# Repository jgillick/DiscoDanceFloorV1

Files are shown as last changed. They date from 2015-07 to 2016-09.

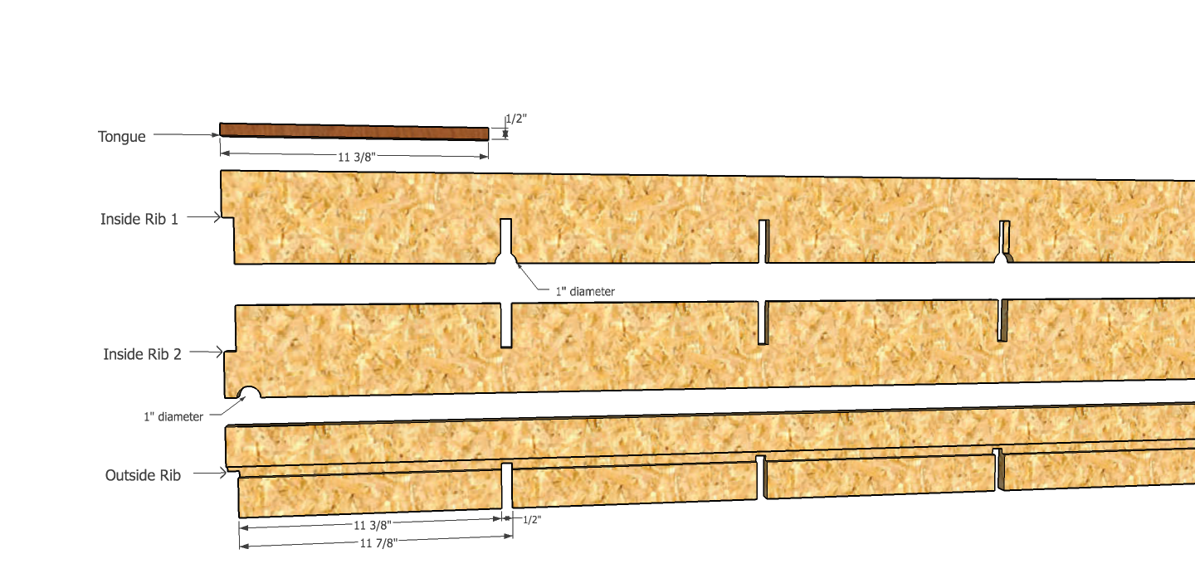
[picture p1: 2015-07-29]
Construction/Exports/RibDimensions.png

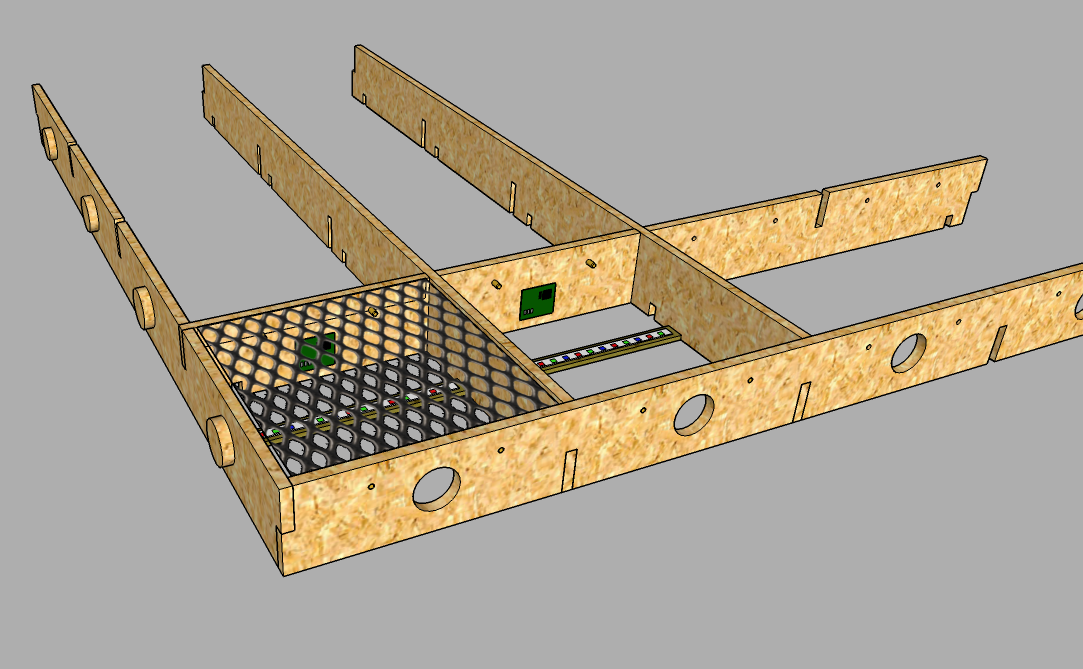
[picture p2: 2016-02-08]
Construction/Exports/FloorCell2.png

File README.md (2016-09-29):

# Disco Dance Floor

Saturday night fever

This project is for a full-size interactive dance floor that can respond to touch and sound.

The floor is made up of individually controlled squares (nodes) attached to a computer via an
RS485 bus. Each node has an Atmega328 with RGB LEDs and a capacitive sensor to detect someone
standing over that cell.

The master controller uses Node.js and provides a simple API that can be used to
write custom floor control programs.

## More information
More information about the build can be found on my page at [hackaday.io](https://hackaday.io/project/4209-interactive-disco-dance-floor).

Touch sensors

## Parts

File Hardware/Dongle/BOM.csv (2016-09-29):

Id | Designator | Package | Quantity | Designation | Supplier and ref
1 | J1 | RJ45_8 | 1 | RJ45
2 | P1 | USB_B | 1 | USB_B
3 | D2 | LED_0805 | 1 | RX
4 | D1 | LED_0805 | 1 | TX
5 | R1,R2,R4,R3 | R_0805 | 4 | 200
6 | C1,C4,C5 | C_0805 | 3 | 100nF
7 | C2 | C_0805 | 1 | 4.7uF
8 | C3 | C_0805 | 1 | 10nF
9 | D3 | LED_0805 | 1 | D
10 | D4 | LED_0805 | 1 | S
11 | R5,R6,R8 | R_0805 | 3 | 20k
12 | R7 | R_0805 | 1 | 120
13 | U1 | SSOP-28_5.3x10.2mm_Pitch0.65mm | 1 | FT232RL
14 | U2 | SOIC-8_3.9x4.9mm_Pitch1.27mm | 1 | ISL81487E

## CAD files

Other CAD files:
Construction/Components/ComputerStickCase.skp
Construction/Components/LED Strip.skp
Construction/Components/Rib Inside 1.skp
Construction/Components/Rib Inside 2.skp
Construction/Components/Rib Outside 1.skp
Construction/Components/Rib Outside 2.skp
Construction/Components/Tongue.skp
Construction/FloorCell.skp
Construction/FloorSection.skp
Construction/RibDimensions.skp

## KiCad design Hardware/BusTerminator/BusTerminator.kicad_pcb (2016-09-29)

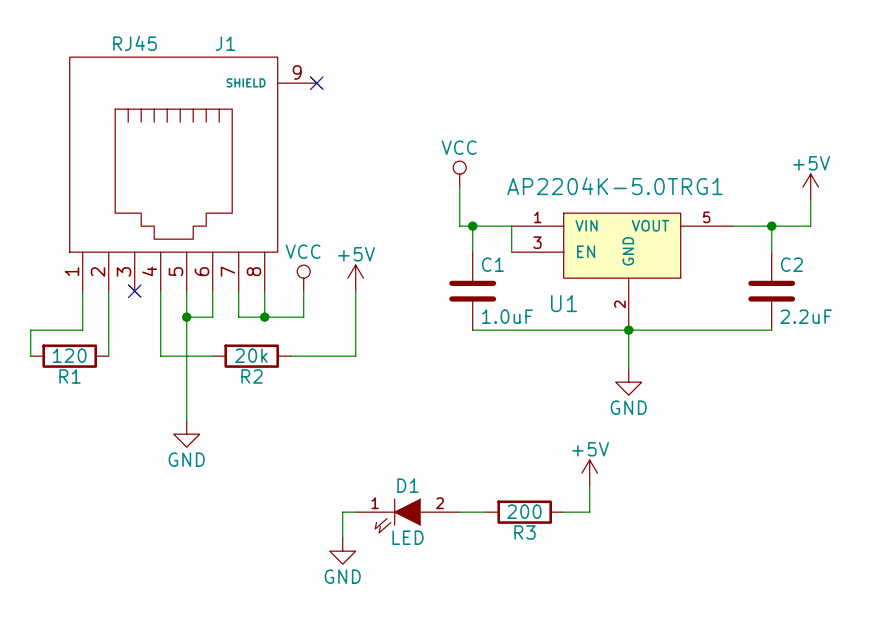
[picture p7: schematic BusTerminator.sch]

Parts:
C1: 1.0uF; C_0805
C2: 2.2uF; C_0805
D1: LED; LED_0805
J1: RJ45; RJ45_8
R1: 120; R_0805
R2: 20k; R_0805
R3: 200; R_0805
U1: AP2204K-5.0TRG1; SOT-23-5

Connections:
+5V: C2.1, R2.1, R3.1, U1.5 (VOUT)
GND: C1.2, C2.2, D1.1 (K), J1.5, J1.6, U1.2 (GND)
unnamed: D1.2 (A), R3.2
unnamed: J1.1, R1.2
unnamed: J1.2, R1.1
unnamed: J1.4, R2.2
VCC: C1.1, J1.7, J1.8, U1.1 (VIN), U1.3 (EN)

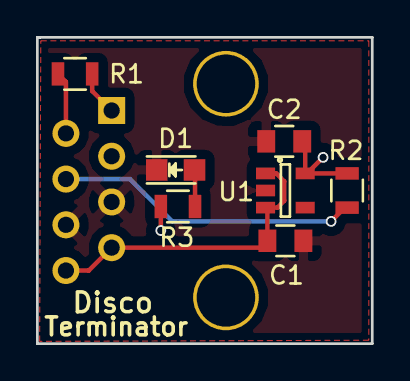
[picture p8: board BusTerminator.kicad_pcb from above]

Board: 2 copper layers, 18.6 x 17.0 mm, 8 parts (1 on the bottom side), 7 nets.

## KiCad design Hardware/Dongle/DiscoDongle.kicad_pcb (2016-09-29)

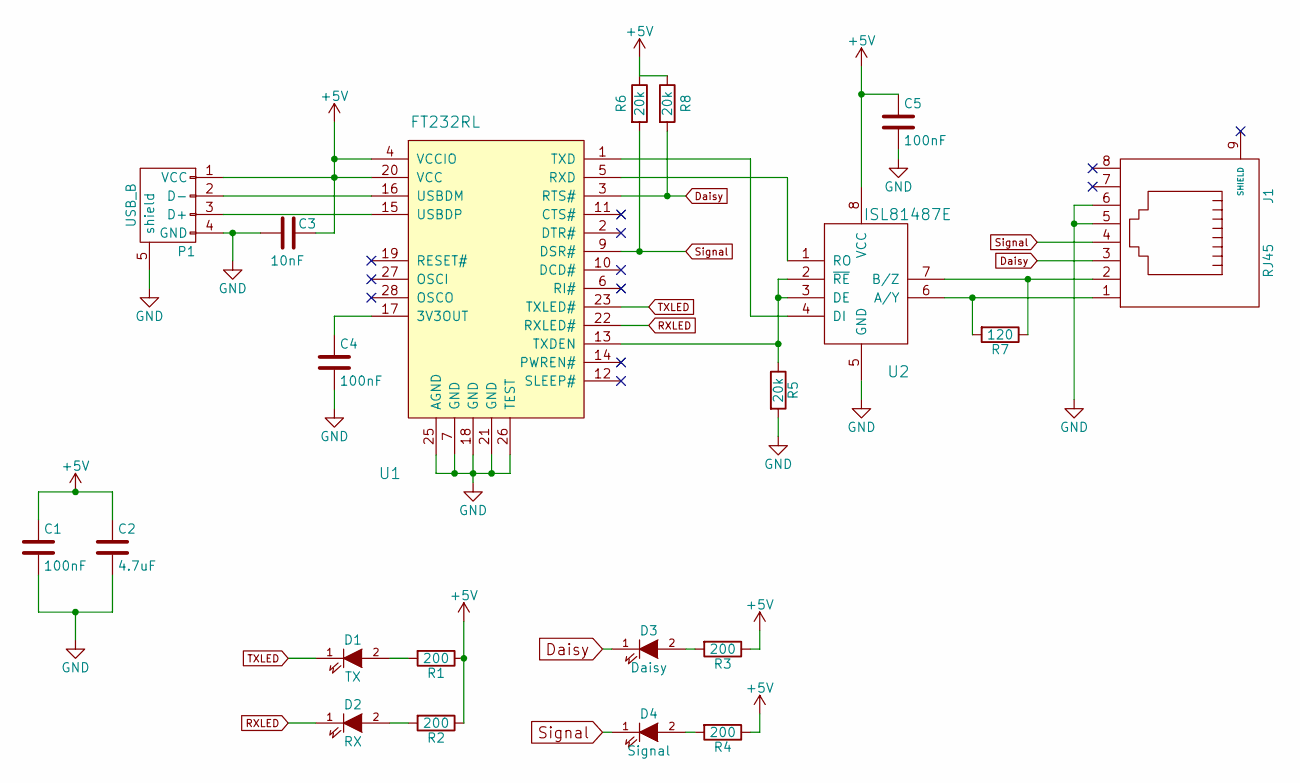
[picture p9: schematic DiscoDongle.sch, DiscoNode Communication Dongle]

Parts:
C1, C4, C5: 100nF; C_0805
C2: 4.7uF; C_0805
C3: 10nF; C_0805
D1: TX; LED_0805
D2: RX; LED_0805
D3: Daisy; LED_0805
D4: Signal; LED_0805
J1: RJ45; RJ45_8
P1: USB_B
R1, R2, R3, R4: 200; R_0805
R5, R6, R8: 20k; R_0805
R7: 120; R_0805
U1: FT232RL; SSOP-28_5.3x10.2mm_Pitch0.65mm
U2: ISL81487E; SOIC-8_3.9x4.9mm_Pitch1.27mm

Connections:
+5V: C1.1, C2.1, C3.1, C5.1, P1.1 (VCC), R1.1, R2.1, R3.1, R4.1, R6.1, R8.1, U1.4 (VCCIO), U1.20 (VCC), U2.8 (VCC)
Daisy: D3.1 (K), J1.3, R8.2, U1.3 (RTS#)
GND: C1.2, C2.2, C3.2, C4.2, C5.2, J1.5, J1.6, P1.4 (GND), P1.5 (shield), R5.2, U1.7 (GND), U1.18 (GND), U1.21 (GND), U1.25 (AGND), U1.26 (TEST), U2.5 (GND)
unnamed: C4.1, U1.17 (3V3OUT)
unnamed: D1.2 (A), R1.2
unnamed: D2.2 (A), R2.2
unnamed: D3.2 (A), R3.2
unnamed: D4.2 (A), R4.2
unnamed: J1.1, R7.2, U2.6 (A/Y)
unnamed: J1.2, R7.1, U2.7 (B/Z)
unnamed: P1.2 (D-), U1.16 (USBDM)
unnamed: P1.3 (D+), U1.15 (USBDP)
unnamed: R5.1, U1.13 (TXDEN), U2.2 (~RE), U2.3 (DE)
unnamed: U1.1 (TXD), U2.4 (DI)
unnamed: U1.5 (RXD), U2.1 (RO)
RXLED: D2.1 (K), U1.22 (RXLED#)
Signal: D4.1 (K), J1.4, R6.2, U1.9 (DSR#)
TXLED: D1.1 (K), U1.23 (TXLED#)

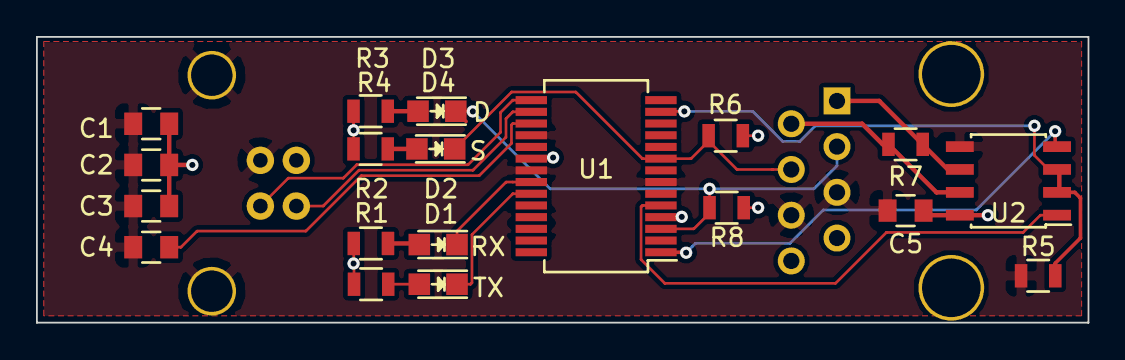
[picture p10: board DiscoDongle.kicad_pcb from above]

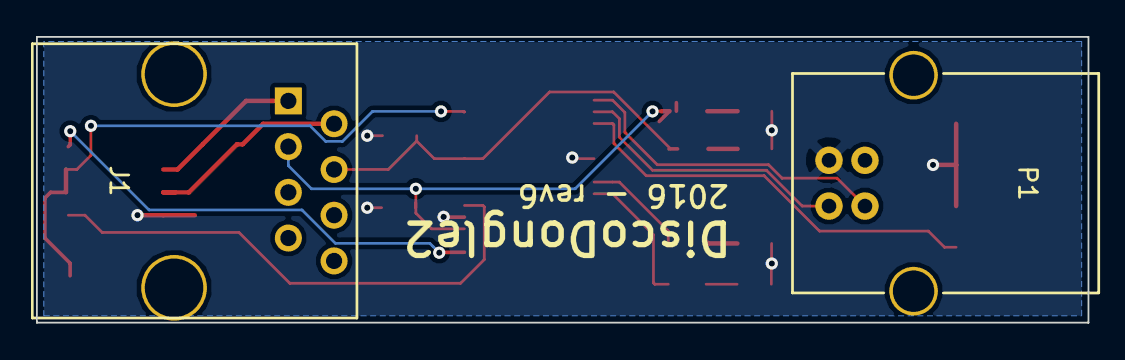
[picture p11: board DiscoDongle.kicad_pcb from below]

Board: 2 copper layers, 58.4 x 15.9 mm, 21 parts (2 on the bottom side), 18 nets.

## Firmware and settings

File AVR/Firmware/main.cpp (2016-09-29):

/*******************************************************************************
* A single disco sqare node.
* 
* This program connects to a multi-drop network as a slave node and 
* waits for the master node to ask it to check the touch sensor and to set the color
* of the RGB LED.
******************************************************************************/

#include <avr/io.h>
#include <avr/wdt.h>
#include <avr/eeprom.h> 

#include "pwm.h"
#include "clock.h"
#include "touch.h"
#include "touch_control.h"
#include "touch_api.h"
#include "MultidropSlave.h"
#include "MultidropData485.h"
#include "version.h"

/*----------------------------------------------------------------------------
                                prototypes
----------------------------------------------------------------------------*/

void comm_init();
void comm_run();
void handle_message();
void handle_response_msg(uint8_t command, uint8_t *buff,uint8_t len);
void set_color(uint8_t *rgb);
void read_sensor();

/*----------------------------------------------------------------------------
                                constants
----------------------------------------------------------------------------*/

#define BUS_BAUD 250000
#define DEFAULT_DETECT_THRES 11u

// Message commands
#define CMD_RESET_NODE       0xFA
#define CMD_SET_ADDRESS      0xFB

#define CMD_GET_VERSION       0xA0
#define CMD_SET_COLOR         0xA1
#define CMD_CHECK_SENSOR      0xA2
#define CMD_SEND_SENSOR_VALUE 0xA3

#define CMD_SET_DETECT_THRESH 0xB0 // Set the QTouch detection threshold

// EEPROM byte addresses

// Since node addresses can go up to 0xFF and EEPROM default values are 0xFF, 
// we need to have an extra byte to tell us if the address has been set.
#define EEPROM_HAS_ADDR      (uint8_t*)0
#define EEPROM_ADDR          (uint8_t*)1
#define EEPROM_DETECT_THRESH (uint8_t*)2

/*----------------------------------------------------------------------------
                          global variables
----------------------------------------------------------------------------*/

// The last touch sensor value
uint8_t sensor_value = 0;
uint8_t reading_sensor = 0;

// Bus serial
MultidropData485 serial(PD2, &DDRD, &PORTD);
MultidropSlave comm(&serial);

/*----------------------------------------------------------------------------
                              program
----------------------------------------------------------------------------*/

/**
 * Main program
 */
int main() {
  wdt_disable();
  wdt_enable(WDTO_2S);

  DDRB |= (1 << PB2); // debug LED
  
  start_clock();
  comm_init();
  pwm_init();

  // Setup touch sensor
  uint8_t detect_threshold = eeprom_read_byte(EEPROM_DETECT_THRESH);
  if (detect_threshold == 0xFF) {
    detect_threshold = DEFAULT_DETECT_THRES;
  }
  touch_init(detect_threshold);

  // Program loop
  while(1) {
    wdt_reset();
    comm_run();
  }
}

/**
 * Initialize the serial communication bus.
 */
void comm_init() {
  // enable pull-up on RX pin
  PORTD |= (1 << PD0);

  serial.begin(BUS_BAUD);
  
  // Define daisy chain lines and let polarity (next/previous) be determined at runtime
  comm.addDaisyChain(PC3, &DDRC, &PORTC, &PINC,
                     PC4, &DDRC, &PORTC, &PINC);

  // Response message handler
  comm.setResponseHandler(&handle_response_msg);

  // Check if we have an address in the EEPROM
  uint8_t addr = eeprom_read_byte(EEPROM_ADDR);
  if (addr > 0 && eeprom_read_byte(EEPROM_HAS_ADDR) == 1) {
    comm.setAddress(addr);
  }
}

/**
 * Read the next bytes from the communication bus and handle any messages.
 */
void comm_run() {
  comm.read();
  if (comm.hasNewMessage() && comm.isAddressedToMe()) {
    handle_message();
  }
}

/**
 * Handle a new message received from the bus.
 */
void handle_message() {
  switch (comm.getCommand()) {
    // We've been assigned an address
    case CMD_SET_ADDRESS:
      if (comm.getAddress() > 0) {
        eeprom_update_byte(EEPROM_HAS_ADDR, 1);
        eeprom_update_byte(EEPROM_ADDR, comm.getAddress());
      }
    break;

    // Reset address saved in the eeprom
    case CMD_RESET_NODE:
      eeprom_update_byte(EEPROM_HAS_ADDR, 0);
      eeprom_update_byte(EEPROM_ADDR, 0);
    break;

    // Set the LED color
    case CMD_SET_COLOR:
      if (comm.getDataLen() == 3) {
        set_color(comm.getData());
      }
    break;

    // Check the touch sensor
    case CMD_CHECK_SENSOR:
      read_sensor();
    break;

    // Set the touch sensor detect threshold
    case CMD_SET_DETECT_THRESH:
      if (comm.getDataLen() == 1) {
        uint8_t dt = comm.getData()[0]; 
        eeprom_update_byte(EEPROM_DETECT_THRESH, dt);
        touch_init(dt);
      }
    break;
  }
}

/**
 * Answer response messages from the bus.
 */
void handle_response_msg(uint8_t command, uint8_t *buff, uint8_t len) {
  switch (comm.getCommand()) {
    // Return our firmware version number
    case CMD_GET_VERSION:
      if (len >= 2) {
        buff[0] = FIRMWARE_VERSION_MAJOR;
        buff[1] = FIRMWARE_VERSION_MINOR;
      }
    break;

    // Send the last sensor value received
    case CMD_SEND_SENSOR_VALUE:
      if (len >= 1) {
        buff[0] = sensor_value;
      }
    break;
  }
}

/**
 * Update RGB LED values
 */
void set_color(uint8_t *rgb) {
  red_pwm(rgb[0]);
  green_pwm(rgb[1]);
  blue_pwm(rgb[2]);
}

/**
 * Get a new reading from the touch sensor.
 */
void read_sensor() {
  if (reading_sensor) return;
  reading_sensor = 1;

  // Default MCU register value
  uint8_t mcuRegister = MCUCR;
  uint16_t status_flag = 0u;

  do {
    // Disable pull-ups
    MCUCR |= (1 << PUD);

    // Measure sensor
    status_flag = qt_measure_sensors( millis() );
    
    // Reset pull-ups
    MCUCR = mcuRegister;

    // Check bus before next measurement
    comm_run();
  } while (status_flag & QTLIB_BURST_AGAIN); // check again, if burst flag is set
  
  // Get sensor value
  sensor_value = GET_SENSOR_STATE(0);
  reading_sensor = 0;

  // Debug LED
  if (sensor_value) {
    PORTB |= (1 << PB2);
  } else {
    PORTB &= ~(1 << PB2);
  }
}

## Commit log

2015-03-07 Add initial prototype
2015-03-07 Fix problem where node stops listening as soon as another node is addressed by removing address filtering from MessageBuffer (still not sure why this was happening
2015-03-08 Add support for LED fading messages
2015-03-08 Update README with Test Master flow
2015-03-08 Update README rs485 transcever wiring
2015-03-09 Add capacitive sensor library
2015-03-09 Change pin numbers to support capacitive touch sensor
2015-03-09 Add capacitive touch sensing!
2015-03-09 Add capacitive touch program
2015-03-13 Use to prevent a deep stack track / recusion
2015-03-13 Add status pin, for debugging
2015-03-17 Speed up status stage, by checking if we're done in the status function (duh)
2015-03-18 Pre-fetch sensor readings to not block status response.
2015-03-21 Change object style (util.inherits doesn't work well with prototype object literal)
2015-03-21 Focus window and add frame rate
2015-03-24 Filter messages that are not for us or master
2015-03-26 Break out Test Master from the main pin map
2015-03-26 Add circuit images
2015-03-26 Add circuit diagram images
2015-03-26 Update RGB LED labels
2015-03-26 Add Fritzing file
    [DiscoFloor.fzz]
2015-03-27 Add arduino breadboard diagram
    [DiscoFloor_Arduino.fzz]
2015-03-30 Move fuse bit section to disco node project
2015-03-30 Add fuse bit section to README
2015-03-30 Update circuit diagrams
    [Arduino.fzz, DiscoFloor.fzz]
2015-03-30 Update BOM
2015-03-30 Add sensor threshold to constants
2015-05-22 Add new non-blocking capacitive sensing library
2015-05-22 Remove timer macros
2015-05-22 Add input change interrupt to detect the sensor value
2015-05-23 Improve stability of data (especially filtered data). Also some house cleaning.
2015-05-28 Add ketchup files
    [FloorCell.skp, FloorSection.skp, LED Strip.skp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]
2015-06-08 Dynamic baseline calibration and other cleanup
2015-06-10 Floor structure updates * Move pass throughs to be at the end of the slots * Remove dowel pin holes * Change hole & pin to tongue and groove.
    [FloorCell.skp, FloorSection.skp, Rib Inside 1.skp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]
2015-06-19 Convert to using input capture method with kalman filter for sensor detection.
2015-06-20 Integrate new cap sensor lib
2015-06-22 Make delay between sensor samples ~5ms Rearrange code
2015-07-27 Rename 'Running Primaries' to 'Primaries' and added a couple more modes
2015-07-27 Program filtering and a "Play All" mode!
2015-07-27 Fix filtering
2015-07-28 Move program code to it's own controller. Add stop button Add program descriptions as tooltips
2015-07-28 Better filtering
2015-07-29 Update time between charging sensor
2015-07-29 Add better program filters
2015-07-31 Update timer interrupt code
2015-08-07 Disable capacitive sensor for now
2015-08-07 Update fuse command
2015-08-07 Optimize communication flow and fix bugs
2015-08-23 Send batch updates in batches of 50 bytes (due to Arduino's 64 byte serial buffer)
2015-09-09 Add disconnect button. Fix color fading with `updateFadeFrame()`. Other code restructuring and cleanup
2016-02-08 Updated construction models
    [ComputerStickCase.skp]
2016-04-29 Make button text bigger.
2016-05-28 Add dongle PCB
    [DiscoDongle-B.Cu.gbl, DiscoDongle-B.Mask.gbs, DiscoDongle-B.SilkS.gbo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]
2016-06-17 Add hardware
    [DiscoNode.gbl, DiscoNode.gbo, DiscoNode.gbp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]
2016-06-20 Update the DiscoDongle with more LEDs and pull-up on daisy line.
    [DiscoDongle-B.Cu.gbl, DiscoDongle-B.Mask.gbs, DiscoDongle-B.Paste.gbp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]
2016-06-22 Tie the RE and DE together on the TXEN line of FTDI
    [DiscoDongle-B.Cu.gbl, DiscoDongle-B.Mask.gbs, DiscoDongle-B.SilkS.gbo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]
2016-06-22 Create bus terminator.
    [BusTerminator.kicad_pcb, BusTerminator.sch]
2016-06-22 Update pours
    [DiscoDongle.kicad_pcb]
2016-06-22 Fix wiring to TXEN and pull-down resistor
    [DiscoDongle.kicad_pcb]
2016-06-30 Add frames per second indicator.
2016-07-04 DiscoDongle - Rev5 - Move components to bottom.
    [DiscoDongle-B.Cu.gbl, DiscoDongle-B.Mask.gbs, DiscoDongle-B.SilkS.gbo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]
2016-07-06 Add emulated touch sensors by clicking on floor cells.
2016-07-09 Firmware works! (sets the LEDs and reports back the sensor value)
2016-07-10 Adjust touch sensor sensitivity and lower false positives.
2016-08-02 Touch sensor tuning
2016-08-08 Save known device list to settings.
2016-08-12 Fix program timer in play all mode.
2016-08-12 Only check sensors for interactive programs.
2016-08-12 Fix error with skipping sensor checks
2016-08-15 Build floor entirely in JS (angular is too slow on raspberry pi)
2016-09-29 Simplify daily/signal connections. Remove FTDI headers.
    [BOM.csv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]
2016-09-29 Remove arduino directory
    [Arduino.fzz, DiscoFloor.fzz]
